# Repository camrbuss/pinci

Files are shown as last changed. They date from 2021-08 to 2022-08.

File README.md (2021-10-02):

# pinci the keyboard 🦐

*pinci pinches panic like popcorn*

This project is still under development, submit an issue if you have questions.

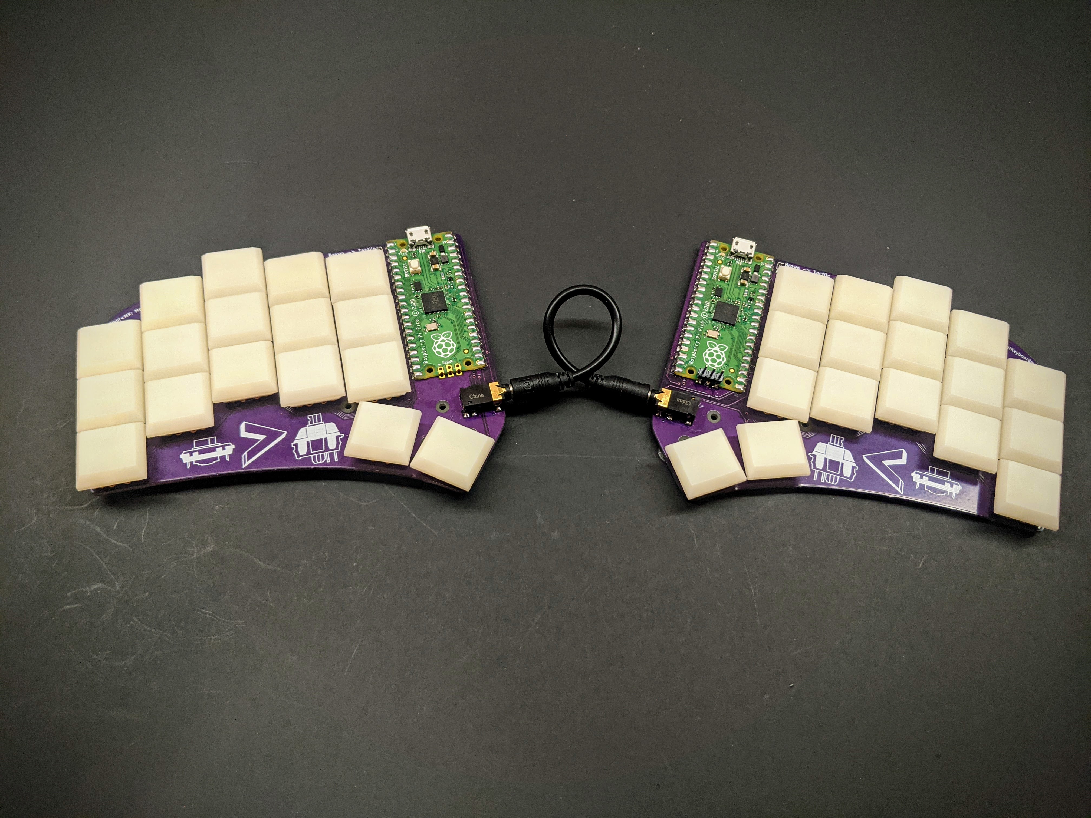
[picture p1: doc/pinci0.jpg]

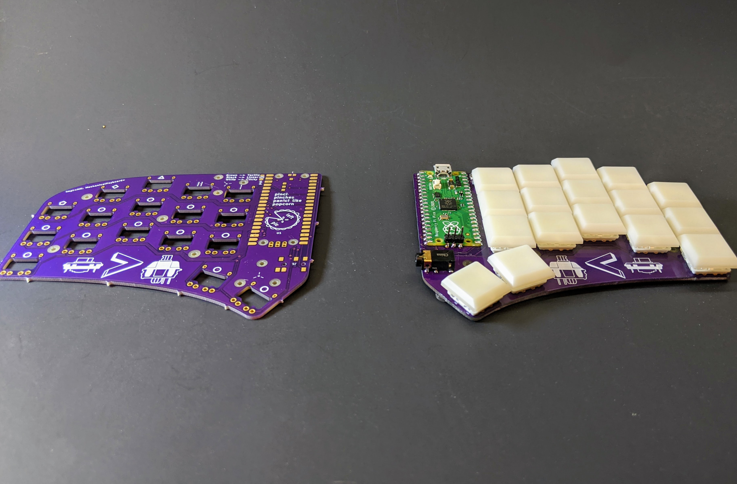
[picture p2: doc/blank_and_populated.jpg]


<p float="left">


</p>

## Hardware

- 34 key layout with two thumb keys skewed outward
- [Kailh PG1232](https://www.kailhswitch.com/news/pg1232-keyboard-switch-brief-introduction-21834938.html) Low Profile Switches
- [Raspberry Pi Pico](https://www.raspberrypi.org/products/raspberry-pi-pico/) (RP2040)
- Reversible PCB
- TRS capable hardware (normal headphone cable)
- Minimal SMD components and no THT components
- No diodes, just direct switch to gpio connections
- Useable with and without a case

### BOM

| Part | Qty | Manufacturer Part No |
| ---- | --- | --- |
| Kailh Swithces | 34 | PG1232 |
| Raspberry Pi Pico | 2 | SC0915 |
| 1206 5% 10k Ohm Resistor | 2 | N/A |
| 3.5mm Headphone Jack | 2 | 54-00177 |

## Firmware

The [firmware](https://github.com/camrbuss/pinci/blob/main/firmware/src/main.rs) is writen in Rust using the following (and more) libraries

- [Keyberon](https://github.com/TeXitoi/keyberon)
- [RTIC](https://github.com/rtic-rs/cortex-m-rtic)
- [rp2040-hal](https://github.com/rp-rs/rp-hal/tree/main/rp2040-hal)

## Inspiration

Thanks to all the open-source projects that have inspired this project

- [Ferris](https://github.com/pierrechevalier83/ferris)
- [Fifi](https://github.com/raychengy/fifi_split_keeb)
- [KeySeeBee](https://github.com/TeXitoi/keyseebee)

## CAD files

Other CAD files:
cad/pinci.FCStd

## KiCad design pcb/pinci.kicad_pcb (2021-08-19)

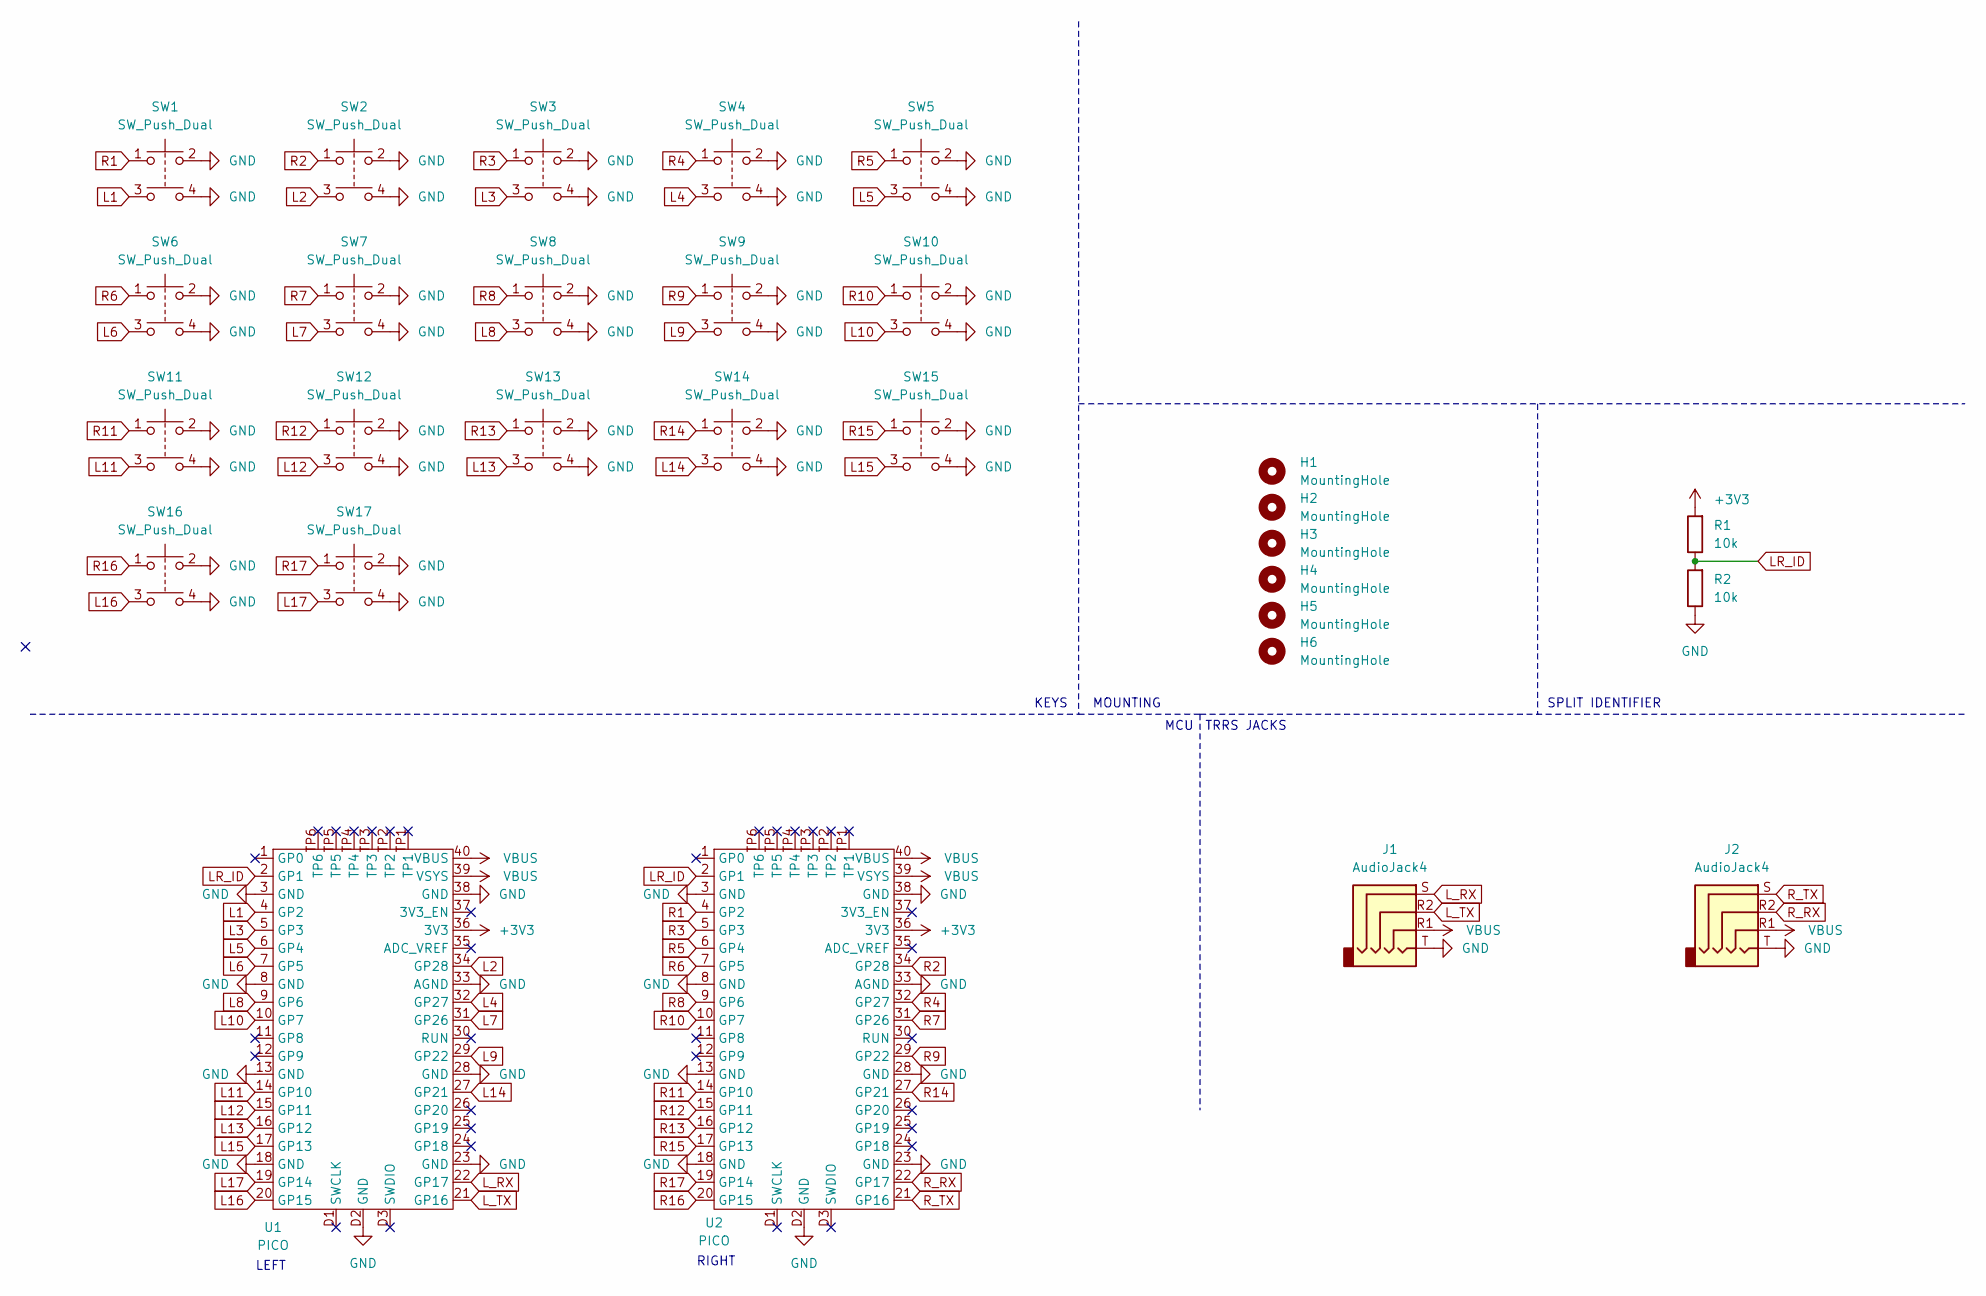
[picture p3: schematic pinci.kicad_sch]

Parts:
H1, H2: MountingHole; 90611A112_Screw_Mount_Nut
H3, H4, H5, H6: MountingHole; M2_Hole
J1, J2: AudioJack4; TRRS_Socket_54-00177
R1, R2: 10k; R_1206_3216Metric_Pad1.30x1.75mm_HandSolder
SW1, SW2, SW3, SW4, SW5, SW6, SW7, SW8, SW9, SW10, SW11, SW12, SW13, SW14, SW15, SW16, SW17: SW_Push_Dual; Kailh_PG1232
U1, U2: PICO; raspberrypi_pico

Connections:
+3V3: R1.2, U1.36 (3V3), U2.36 (3V3)
GND: J1.T, J2.T, R2.1, SW1.2, SW1.4, SW2.2, SW2.4, SW3.2, SW3.4, SW4.2, SW4.4, SW5.2, SW5.4, SW6.2, SW6.4, SW7.2, SW7.4, SW8.2, SW8.4, SW9.2, SW9.4, SW10.2, SW10.4, SW11.2, SW11.4, SW12.2, SW12.4, SW13.2, SW13.4, SW14.2, SW14.4, SW15.2, SW15.4, SW16.2, SW16.4, SW17.2, SW17.4, U1.3 (GND), U1.8 (GND), U1.13 (GND), U1.18 (GND), U1.23 (GND), U1.28 (GND), U1.33 (AGND), U1.38 (GND), U1.D2 (GND), U2.3 (GND), U2.8 (GND), U2.13 (GND), U2.18 (GND), U2.23 (GND), U2.28 (GND), U2.33 (AGND), U2.38 (GND), U2.D2 (GND)
L1: SW1.3, U1.4 (GP2)
L2: SW2.3, U1.34 (GP28)
L3: SW3.3, U1.5 (GP3)
L4: SW4.3, U1.32 (GP27)
L5: SW5.3, U1.6 (GP4)
L6: SW6.3, U1.7 (GP5)
L7: SW7.3, U1.31 (GP26)
L8: SW8.3, U1.9 (GP6)
L9: SW9.3, U1.29 (GP22)
L10: SW10.3, U1.10 (GP7)
L11: SW11.3, U1.14 (GP10)
L12: SW12.3, U1.15 (GP11)
L13: SW13.3, U1.16 (GP12)
L14: SW14.3, U1.27 (GP21)
L15: SW15.3, U1.17 (GP13)
L16: SW16.3, U1.20 (GP15)
L17: SW17.3, U1.19 (GP14)
LR_ID: R1.1, R2.2, U1.2 (GP1), U2.2 (GP1)
L_RX: J1.S, U1.22 (GP17)
L_TX: J1.R2, U1.21 (GP16)
R1: SW1.1, U2.4 (GP2)
R2: SW2.1, U2.34 (GP28)
R3: SW3.1, U2.5 (GP3)
R4: SW4.1, U2.32 (GP27)
R5: SW5.1, U2.6 (GP4)
R6: SW6.1, U2.7 (GP5)
R7: SW7.1, U2.31 (GP26)
R8: SW8.1, U2.9 (GP6)
R9: SW9.1, U2.29 (GP22)
R10: SW10.1, U2.10 (GP7)
R11: SW11.1, U2.14 (GP10)
R12: SW12.1, U2.15 (GP11)
R13: SW13.1, U2.16 (GP12)
R14: SW14.1, U2.27 (GP21)
R15: SW15.1, U2.17 (GP13)
R16: SW16.1, U2.20 (GP15)
R17: SW17.1, U2.19 (GP14)
R_RX: J2.R2, U2.22 (GP17)
R_TX: J2.S, U2.21 (GP16)
VBUS: J1.R1, J2.R1, U1.39 (VSYS), U1.40 (VBUS), U2.39 (VSYS), U2.40 (VBUS)

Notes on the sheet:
LEFT
RIGHT
KEYS
MOUNTING
MCU
TRRS JACKS
SPLIT IDENTIFIER

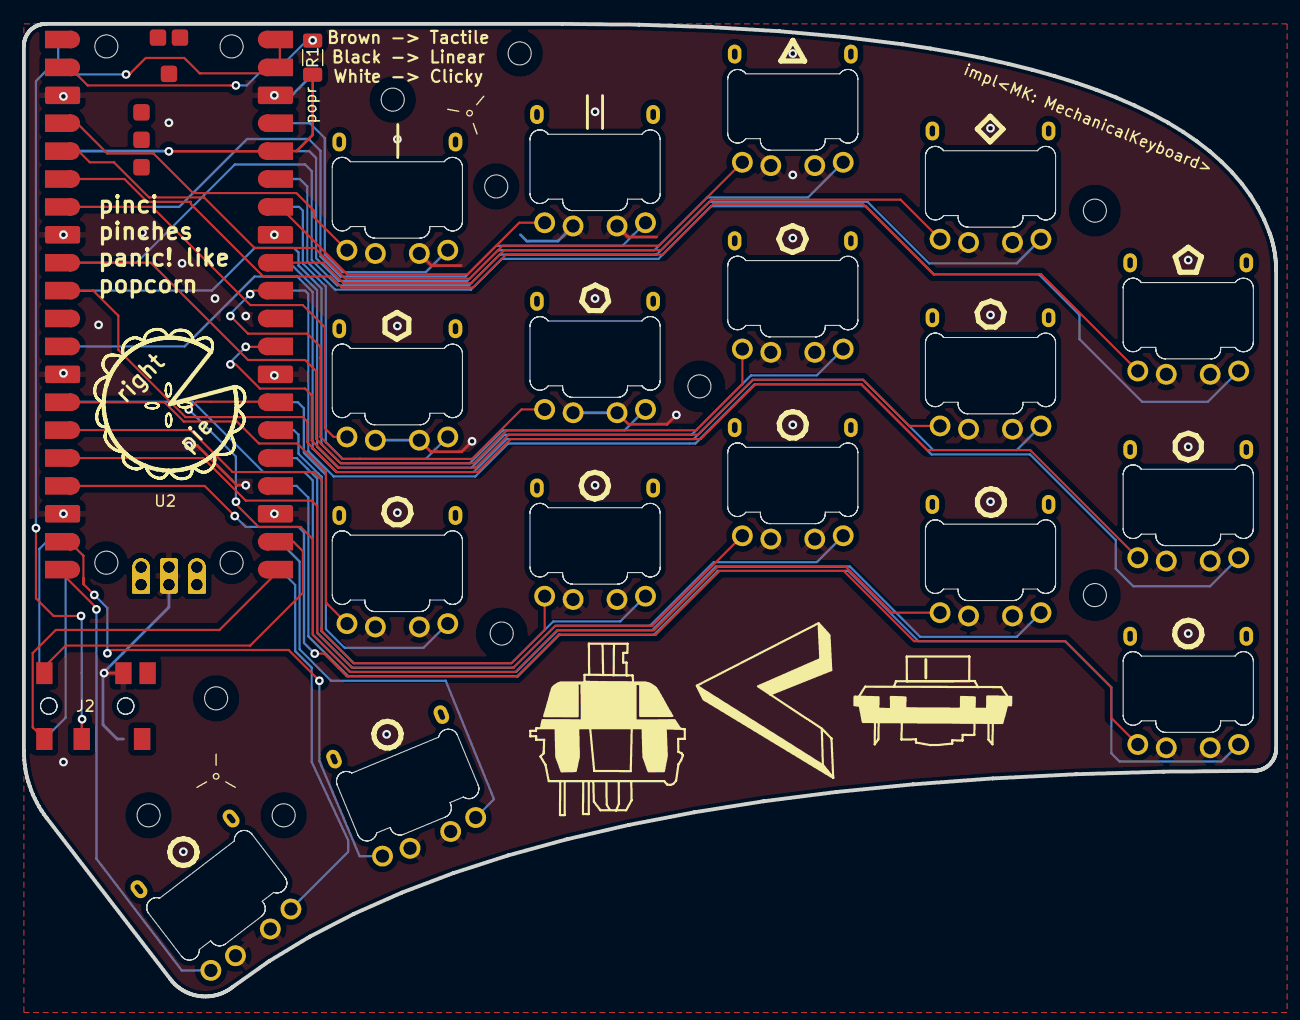
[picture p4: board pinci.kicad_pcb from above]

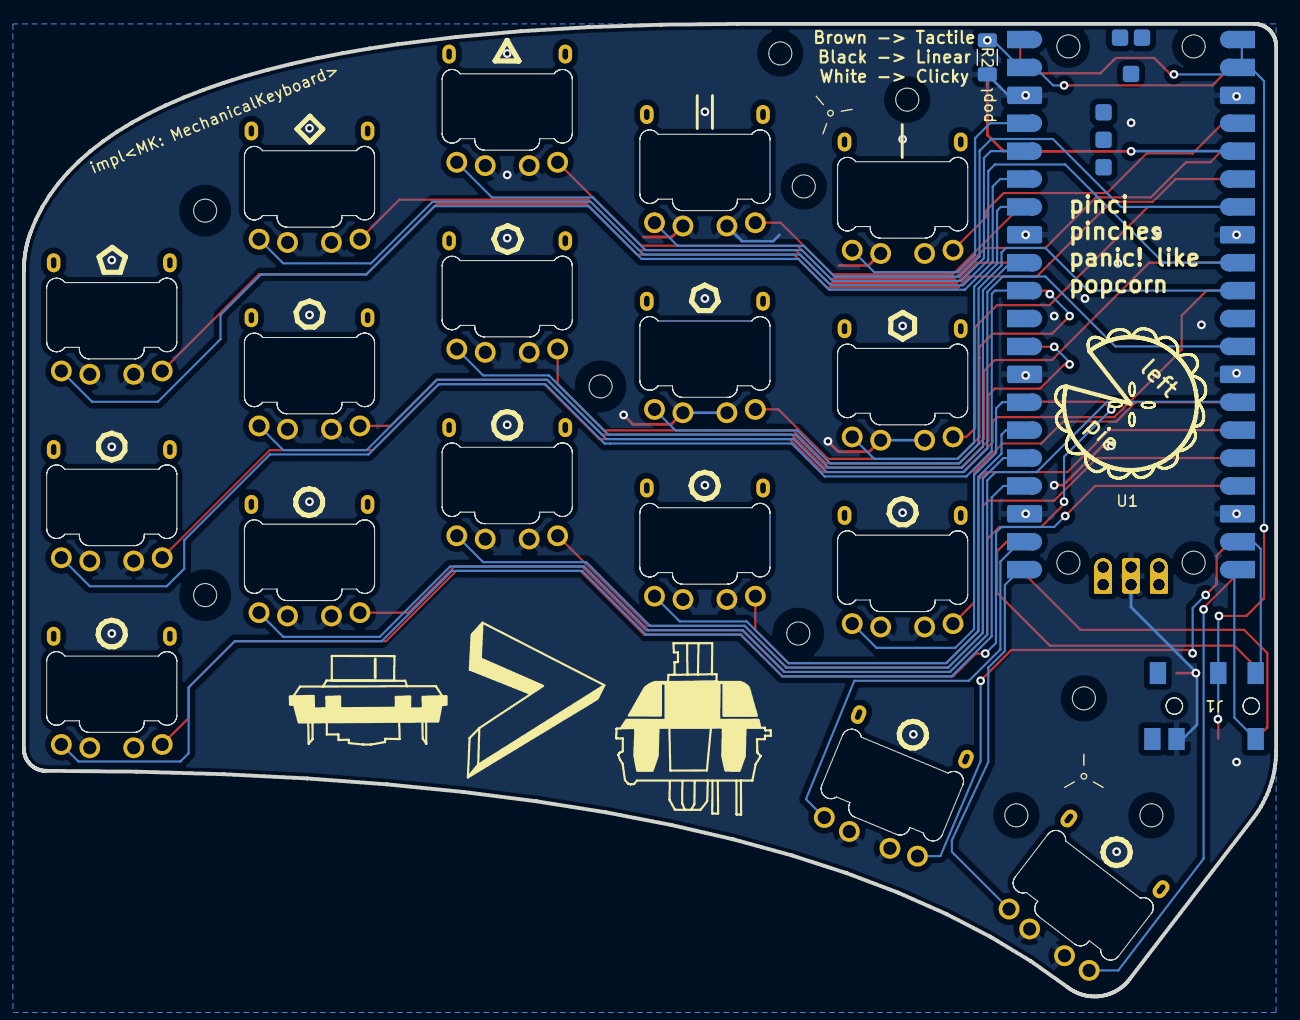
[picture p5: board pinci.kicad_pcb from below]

Board: 2 copper layers, 114.0 x 88.5 mm, 29 parts (5 on the bottom side), 42 nets.

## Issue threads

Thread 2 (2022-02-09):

Kailh Choc switches

hanslenze, 2022-02-09:
Since Kailh Choc Mini switches (PG1232) are so hard to get. Can you make a version that uses "normal" low profile Kailh Choc switches (PG1350)?

camrbuss, 2022-02-10:
It looks like you can still buy the PG1232 on Kailh's aliexpress store. https://www.aliexpress.com/item/32989908397.html?spm=a2g0o.9042311.0.0.40af4c4djiMwT9

If you really want the PG1350, you could definitely just change the footprint and then just update the board. Should be pretty easy.

hanslenze, 2022-02-14:
Thank you so much for that link! I'll make a Choc Mini version when they get to my doorstep.

Closed 2022-02-14.

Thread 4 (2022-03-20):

Mounting holes for what?

hanslenze, 2022-03-20:
I've finally received my PCB order and now I'm wondering what the various mounting holes on this PCB are designed to mount.
Are the two triangular positions meant for a tenting kit? The four holes around the Pico match the Pico itself so they are obvious.
Are the other five holes are for screwing a case to the bottom?

camrbuss, 2022-03-20:
Wow, I'm honored you are taking the dive with the PCB order!

The 5 holes can be used for plate mounting or tenting, and the sets of three are meant to mount one of these nuts (https://www.mcmaster.com/nuts/surface-mount-nuts/)

I never used any of the mount points as I liked keeping it really thin.

Let me know how it works out! I'm happy to work software updates now that someone else has hardware.

camrbuss, 2022-04-01:
@hanslenze Any update or pictures of your build?

hanslenze, 2022-04-01:
I can share my current progress, sure!
Almost all the components have been gathered in a box and now I'm trying to gather enough courage to start the soldering :)
The Pico itself is a bit more SMD soldering so in my head that seems like the hardest part. I've got a temparature controlled soldering iron with a small tip, a fluxpen and 0,6mm resin core solder ready to go.
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

hanslenze, 2022-04-20:
After a few days of use I can say I really like the shape and size of the keyboard but I'm not so sure about the keys themselves. They seem stiff. Maybe it will improve with use, maybe I'll remove the clickbar or lube them or something. Ringfinger and pinky could use a little lighter keys for improved typing comfort and less typing errors. The spit feels great and the column stagger fits my hand very well.
With lots of help from a colleague I've set up the Rust build environment. My first attempt at a keymap can be found on this page: https://github.com/hanslenze/Pinci
The thing I'm missing most is a "mouse mode" where I can move the mouse pointer and use the clicking and scroll keys of a normal mouse. I'm used to that from using a keyboard with QMK. I feel like it is somehow wasteful to use such a powerful chip to only register key presses and nothing else. Maybe I'll add a display or try something else with the pins, memory and processing power that is left on both the Pico's.
Right now it's boring black on black but I'm hoping the fancy coloured MBK keycaps are available at my favorite keyboard shop soon. I've made two of my colleagues happy with a set of PCBs each so they are going to make a Pinci keyboard too.
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

camrbuss, 2022-04-21:
Love the build! Hope it has been fun.

I also can't say I love the switches as far as feel goes. I took my click bars out and it honestly feels even more squishy.

There are some rust/keyberon firmwares out there with mouse emulation so there is opportunity for improvement. I'll try to get this repo updates with firmware with more features.

Have fun playing around!

hanslenze, 2022-11-20:
Just a message to let you know I've made a QMK firmware for the Pinci. I've put a complete version in my Github repo: https://github.com/hanslenze/Pinci-QMK Feel free to copy, use, etc.
Still love the shape, size and features of it so I will be ordering a new batch of PCBs with Kailh Choc hot swap sockets so I can use "normal" low profile keys. Maybe I'll add an I2C header so I can connect a Cirque trackpad. We'll see!

camrbuss, 2022-11-20:
> Just a message to let you know I've made a QMK firmware for the Pinci. I've put a complete version in my Github repo: https://github.com/hanslenze/Pinci-QMK Feel free to copy, use, etc. Still love the shape, size and features of it so I will be ordering a new batch of PCBs with Kailh Choc hot swap sockets so I can use "normal" low profile keys. Maybe I'll add an I2C header so I can connect a Cirque trackpad. We'll see!

Awesome! Thanks for sharing! I'm so glad to see you having fun modifying it. It's lovely to to see some more pinci's in the world.

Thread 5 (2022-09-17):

can gateron low profiles work on the pinci ?

dapppss, 2022-09-17:
im just wondering if they work instead of kailh chocs since gaterons are a bit cheaper.

camrbuss, 2022-10-17:
Sorry, they will not work. Please see the Bill of Materials.

Closed 2022-10-17.

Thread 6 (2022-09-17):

do i need to tweak the specs on pcbway on can i just leave it on deafult

dapppss, 2022-09-17:
i have the gerber file on pcbway but i don't know if i just leave the specs eg size etc. or if i just leave on the defult settings.

camrbuss, 2022-09-24:
> i have the gerber file on pcbway but i don't know if i just leave the specs eg size etc. or if i just leave on the defult settings.

Did you resolve this? I was away when you created the issue.

Closed 2022-09-23.

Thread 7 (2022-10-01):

Are there any build guide?

KentaroKoga, 2022-10-01:
I'm beginner to raspberry pi keyboard so just worried if I can build and set it up properly without guide.
I have experience of building sweep and cantor but not raspberry pi.

I'm sorry if you already put a guide somewhere and I just didn't find it.

Thanks a lot for making this✨

camrbuss, 2022-10-01:
I don't have a build guide as you just solder on the Raspberry Pi Pico, the one resistor (popl or popr), the 3.5mm jack, and then the switches.

Besides soldering the resistor and jack before everything else, there is no special order you need to follow.

I'm happy to answer questions if you decide to attempt the build. If you are new to diy electronics this might not be the best start, but it is certainly possible.

Thanks for the interest! 🦀

KentaroKoga, 2022-10-02:
Thanks for your reply! I think I'll give it a try:)

Closed 2022-10-02.

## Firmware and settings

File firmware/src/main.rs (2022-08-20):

#![no_std]
#![no_main]

use panic_halt as _;

#[rtic::app(device = rp_pico::hal::pac, peripherals = true, dispatchers = [PIO0_IRQ_0])]
mod app {
    use cortex_m::prelude::_embedded_hal_watchdog_Watchdog;
    use cortex_m::prelude::_embedded_hal_watchdog_WatchdogEnable;
    use embedded_hal::digital::v2::{InputPin, OutputPin};
    use embedded_time::duration::units::*;
    use keyberon::action::{k, l, Action, HoldTapAction, HoldTapConfig};
    use keyberon::chording::{ChordDef, Chording};
    use keyberon::debounce::Debouncer;
    use keyberon::key_code::{self, KeyCode::*};
    use keyberon::layout::{self, Layout};
    use keyberon::matrix::Matrix;
    use rp_pico::{
        hal::{
            self, clocks::init_clocks_and_plls, gpio::DynPin, sio::Sio, timer::Alarm, usb::UsbBus,
            watchdog::Watchdog,
        },
        XOSC_CRYSTAL_FREQ,
    };
    use usb_device::class_prelude::*;
    use usb_device::device::UsbDeviceState;

    const SCAN_TIME_US: u32 = 1000;
    static mut USB_BUS: Option<usb_device::bus::UsbBusAllocator<rp2040_hal::usb::UsbBus>> = None;

    #[derive(Debug, Clone, Copy, Eq, PartialEq)]
    pub enum CustomActions {
        Uf2,
        Reset,
    }
    const UF2: Action<CustomActions> = Action::Custom(CustomActions::Uf2);
    const RESET: Action<CustomActions> = Action::Custom(CustomActions::Reset);

    const QW_ESC: ChordDef = ((0, 37), &[(0, 0), (0, 1)]);
    const JU_ESC: ChordDef = ((0, 37), &[(0, 16), (0, 6)]);
    const KI_TAB: ChordDef = ((0, 39), &[(0, 17), (0, 7)]);
    const LO_ENTER: ChordDef = ((0, 38), &[(0, 18), (0, 8)]);
    const CHORDS: [ChordDef; 4] = [QW_ESC, JU_ESC, KI_TAB, LO_ENTER];

    const A_LSHIFT: Action<CustomActions> = Action::HoldTap(&HoldTapAction {
        timeout: 200,
        hold: k(LShift),
        tap: k(A),
        config: HoldTapConfig::PermissiveHold,
        tap_hold_interval: 0,
    });
    const L5_S: Action<CustomActions> = Action::HoldTap(&HoldTapAction {
        timeout: 200,
        hold: l(5),
        tap: k(S),
        config: HoldTapConfig::Default,
        tap_hold_interval: 0,
    });
    const D_LALT: Action<CustomActions> = Action::HoldTap(&HoldTapAction {
        timeout: 200,
        hold: k(LAlt),
        tap: k(D),
        config: HoldTapConfig::Default,
        tap_hold_interval: 0,
    });
    const L2_F: Action<CustomActions> = Action::HoldTap(&HoldTapAction {
        timeout: 200,
        hold: l(2),
        tap: k(F),
        config: HoldTapConfig::Default,
        tap_hold_interval: 0,
    });
    const DOT_RALT: Action<CustomActions> = Action::HoldTap(&HoldTapAction {
        timeout: 200,
        hold: k(RAlt),
        tap: k(Dot),
        config: HoldTapConfig::Default,
        tap_hold_interval: 0,
    });
    const X_LALT: Action<CustomActions> = Action::HoldTap(&HoldTapAction {
        timeout: 200,
        hold: k(LAlt),
        tap: k(X),
        config: HoldTapConfig::Default,
        tap_hold_interval: 0,
    });
    const SLASH_RCTRL: Action<CustomActions> = Action::HoldTap(&HoldTapAction {
        timeout: 200,
        hold: k(RCtrl),
        tap: k(Slash),
        config: HoldTapConfig::Default,
        tap_hold_interval: 0,
    });
    const Z_LCTRL: Action<CustomActions> = Action::HoldTap(&HoldTapAction {
        timeout: 200,
        hold: k(LCtrl),
        tap: k(Z),
        config: HoldTapConfig::Default,
        tap_hold_interval: 0,
    });
    const L4_C: Action<CustomActions> = Action::HoldTap(&HoldTapAction {
        timeout: 200,
        hold: l(4),
        tap: k(C),
        config: HoldTapConfig::Default,
        tap_hold_interval: 0,
    });
    const SEMI_RSHIFT: Action<CustomActions> = Action::HoldTap(&HoldTapAction {
        timeout: 200,
        hold: k(RShift),
        tap: k(SColon),
        config: HoldTapConfig::PermissiveHold,
        tap_hold_interval: 0,
    });
    const L7_SPACE: Action<CustomActions> = Action::HoldTap(&HoldTapAction {
        timeout: 200,
        hold: l(7),
        tap: k(Space),
        config: HoldTapConfig::Default,
        tap_hold_interval: 0,
    });
    const L4_COMMA: Action<CustomActions> = Action::HoldTap(&HoldTapAction {
        timeout: 200,
        hold: l(4),
        tap: k(Comma),
        config: HoldTapConfig::Default,
        tap_hold_interval: 0,
    });

    #[rustfmt::skip]
    pub static LAYERS: keyberon::layout::Layers<40, 1, 8, CustomActions> = keyberon::layout::layout! {
    {[ // 0
        Q          W        E        R      T      Y          U   I          O          P
        {A_LSHIFT} {L5_S}   {D_LALT} {L2_F} G      H          J   K          L          {SEMI_RSHIFT}
        {Z_LCTRL}  {X_LALT} {L4_C}   V      B      N          M   {L4_COMMA} {DOT_RALT} {SLASH_RCTRL}
        t          t        t        (3)    BSpace {L7_SPACE} Tab Escape     Enter      Tab
    ]}
    {[ // 1
        t t t t t t t t t t
        t t t t t t t t t t
        t t t t t t t t t t
        t t t t t t t t t t
    ]}
    {[ // 2
        t t t t t * 7 8 9 +
        t t t t t / 4 5 6 -
        t t t t t . 1 2 3 .
        t t t t t 0 0 t t t
    ]}
    {[ // 3
        t 7 8 9 t t t t t t
        t 4 5 6 t t t t t t
        0 1 2 3 t t t t t t
        t t t t t t t t t t
    ]}
    {[ // 4
        !   @   #   $   % t ~   |    '`' +
        '{' '}' '(' ')' t = '_' -    '"' Quote
        '[' ']' ^   &   * t /   '\\' t   t
        t   t   t   t   t t t   t    t   t
    ]}
    {[ // 5
        t t t      t t t    t    PgUp   t     t
        t t Delete t t Left Down Up     Right Enter
        t t t      t t t    Home PgDown End   t
        t t t      t t t    t    t      t     t
    ]}
    {[ // 6
        {RESET} {UF2} t t t t t t t MediaSleep
        t       t     t t t t t t t t
        t       t     t t t t t t t t
        t       t     t t t t t t t t
    ]}
    {[ // 7
        t t t t t      MediaNextSong MediaPlayPause MediaVolDown MediaVolUp PScreen
        t t t t t      t             Escape         Tab          Enter      Enter
        t t t t t      t             t              t            t          Delete
        t t t t Delete t             t              t            t          t
    ]}

};

    #[shared]
    struct Shared {
        usb_dev: usb_device::device::UsbDevice<'static, rp2040_hal::usb::UsbBus>,
        usb_class: keyberon::hid::HidClass<
            'static,
            rp2040_hal::usb::UsbBus,
            keyberon::keyboard::Keyboard<()>,
        >,
        uart: rp2040_hal::pac::UART0,
        layout: Layout<40, 1, 8, CustomActions>,
    }

    #[local]
    struct Local {
        watchdog: hal::watchdog::Watchdog,
        chording: Chording<4>,
        matrix: Matrix<DynPin, DynPin, 17, 1>,
        debouncer: Debouncer<[[bool; 17]; 1]>,
        alarm: hal::timer::Alarm0,
        transform: fn(layout::Event) -> layout::Event,
        is_right: bool,
    }

    #[init]
    fn init(c: init::Context) -> (Shared, Local, init::Monotonics) {
        // Soft-reset does not release the hardware spinlocks
        // Release them now to avoid a deadlock after debug or watchdog reset
        unsafe {
            hal::sio::spinlock_reset();
        }
        let mut resets = c.device.RESETS;
        let mut watchdog = Watchdog::new(c.device.WATCHDOG);
        let clocks = init_clocks_and_plls(
            XOSC_CRYSTAL_FREQ,
            c.device.XOSC,
            c.device.CLOCKS,
            c.device.PLL_SYS,
            c.device.PLL_USB,
            &mut resets,
            &mut watchdog,
        )
        .ok()
        .unwrap();

        let sio = Sio::new(c.device.SIO);
        let pins = hal::gpio::Pins::new(
            c.device.IO_BANK0,
            c.device.PADS_BANK0,
            sio.gpio_bank0,
            &mut resets,
        );

        // 17 input pins and 1 empty pin that is not really used, but
        // is needed by keyberon as a "row"
        let gpio2 = pins.gpio2;
        let gpio28 = pins.gpio28;
        let gpio3 = pins.gpio3;
        let gpio27 = pins.gpio27;
        let gpio4 = pins.gpio4;
        let gpio5 = pins.gpio5;
        let gpio26 = pins.gpio26;
        let gpio6 = pins.gpio6;
        let gpio22 = pins.gpio22;
        let gpio7 = pins.gpio7;
        let gpio10 = pins.gpio10;
        let gpio11 = pins.gpio11;
        let gpio12 = pins.gpio12;
        let gpio21 = pins.gpio21;
        let gpio13 = pins.gpio13;
        let gpio15 = pins.gpio15;
        let gpio14 = pins.gpio14;

        let gpio20 = pins.gpio20;

        let mut led = pins.gpio25.into_push_pull_output();
        // GPIO1 is high for the right hand side
        let side = pins.gpio1.into_floating_input();
        // delay for power on
        for _ in 0..1000 {
            cortex_m::asm::nop();
        }

        // Use a transform to get correct layout from right and left side
        let is_right = side.is_high().unwrap();
        let transform: fn(layout::Event) -> layout::Event = if is_right {
            |e| {
                e.transform(|i: u8, j: u8| -> (u8, u8) {
                    // 0 -> 5,  5 -> 15, 10 -> 25
                    let x = ((j / 5) * 10) + (j % 5) + 5;
                    (i, x)
                })
            }
        } else {
            |e| {
                e.transform(|i: u8, j: u8| -> (u8, u8) {
                    let x = ((j / 5) * 10) + 4 - (j % 5);
                    (i, x)
                })
            }
        };

        // Enable UART0
        resets.reset.modify(|_, w| w.uart0().clear_bit());
        while resets.reset_done.read().uart0().bit_is_clear() {}
        let uart = c.device.UART0;
        uart.uartibrd.write(|w| unsafe { w.bits(0b0100_0011) });
        uart.uartfbrd.write(|w| unsafe { w.bits(0b0011_0100) });
        uart.uartlcr_h.write(|w| unsafe { w.bits(0b0110_0000) });
        uart.uartcr.write(|w| unsafe { w.bits(0b11_0000_0001) });
        uart.uartimsc.write(|w| w.rxim().set_bit());

        let matrix: Matrix<DynPin, DynPin, 17, 1> = Matrix::new(
            [
                gpio2.into_pull_up_input().into(),
                gpio28.into_pull_up_input().into(),
                gpio3.into_pull_up_input().into(),
                gpio27.into_pull_up_input().into(),
                gpio4.into_pull_up_input().into(),
                gpio5.into_pull_up_input().into(),
                gpio26.into_pull_up_input().into(),
                gpio6.into_pull_up_input().into(),
                gpio22.into_pull_up_input().into(),
                gpio7.into_pull_up_input().into(),
                gpio10.into_pull_up_input().into(),
                gpio11.into_pull_up_input().into(),
                gpio12.into_pull_up_input().into(),
                gpio21.into_pull_up_input().into(),
                gpio13.into_pull_up_input().into(),
                gpio15.into_pull_up_input().into(),
                gpio14.into_pull_up_input().into(),
            ],
            [gpio20.into_push_pull_output().into()],
        )
        .unwrap();

        let layout = Layout::new(&LAYERS);
        let debouncer = Debouncer::new([[false; 17]; 1], [[false; 17]; 1], 20);

        let chording = Chording::new(&CHORDS);

        let mut timer = hal::Timer::new(c.device.TIMER, &mut resets);
        let mut alarm = timer.alarm_0().unwrap();
        let _ = alarm.schedule(SCAN_TIME_US.microseconds());
        alarm.enable_interrupt();

        // TRS cable only supports one direction of communication
        if is_right {
            let _rx_pin = pins.gpio17.into_mode::<hal::gpio::FunctionUart>();
            led.set_high().unwrap();
        } else {
            let _tx_pin = pins.gpio16.into_mode::<hal::gpio::FunctionUart>();
        }

        let usb_bus = UsbBusAllocator::new(UsbBus::new(
            c.device.USBCTRL_REGS,
            c.device.USBCTRL_DPRAM,
            clocks.usb_clock,
            true,
            &mut resets,
        ));
        unsafe {
            USB_BUS = Some(usb_bus);
        }
        let usb_class = keyberon::new_class(unsafe { USB_BUS.as_ref().unwrap() }, ());
        let usb_dev = keyberon::new_device(unsafe { USB_BUS.as_ref().unwrap() });

        // Start watchdog and feed it with the lowest priority task at 1000hz
        watchdog.start(10_000.microseconds());

        (
            Shared {
                usb_dev,
                usb_class,
                uart,
                layout,
            },
            Local {
                alarm,
                chording,
                watchdog,
                matrix,
                debouncer,
                transform,
                is_right,
            },
            init::Monotonics(),
        )
    }

    #[task(binds = USBCTRL_IRQ, priority = 3, shared = [usb_dev, usb_class])]
    fn usb_rx(c: usb_rx::Context) {
        let mut usb_d = c.shared.usb_dev;
        let mut usb_c = c.shared.usb_class;
        usb_d.lock(|d| {
            usb_c.lock(|c| {
                if d.poll(&mut [c]) {
                    c.poll();
                }
            })
        });
    }

    #[task(priority = 2, capacity = 8, shared = [usb_dev, usb_class, layout])]
    fn handle_event(mut c: handle_event::Context, event: Option<layout::Event>) {
        match event {
            // TODO: Support Uf2 for the side not performing USB HID
            // The right side only passes None here and buffers the keys
            // for USB to send out when polled by the host
            None => match c.shared.layout.lock(|l| l.tick()) {
                layout::CustomEvent::Press(event) => match event {
                    CustomActions::Uf2 => {
                        hal::rom_data::reset_to_usb_boot(0, 0);
                    }
                    CustomActions::Reset => {
                        cortex_m::peripheral::SCB::sys_reset();
                    }
                },
                _ => (),
            },
            Some(e) => {
                c.shared.layout.lock(|l| l.event(e));
                return;
            }
        };
        let report: key_code::KbHidReport = c.shared.layout.lock(|l| l.keycodes().collect());
        if !c
            .shared
            .usb_class
            .lock(|k| k.device_mut().set_keyboard_report(report.clone()))
        {
            return;
        }
        if c.shared.usb_dev.lock(|d| d.state()) != UsbDeviceState::Configured {
            return;
        }
        while let Ok(0) = c.shared.usb_class.lock(|k| k.write(report.as_bytes())) {}
    }

    #[task(
        binds = TIMER_IRQ_0,
        priority = 1,
        shared = [uart],
        local = [matrix, debouncer, chording, watchdog, alarm, transform, is_right],
    )]
    fn scan_timer_irq(mut c: scan_timer_irq::Context) {
        let alarm = c.local.alarm;
        alarm.clear_interrupt();
        let _ = alarm.schedule(SCAN_TIME_US.microseconds());

        c.local.watchdog.feed();
        let keys_pressed = c.local.matrix.get().unwrap();
        let deb_events = c
            .local
            .debouncer
            .events(keys_pressed)
            .map(c.local.transform);
        // TODO: right now chords cannot only be exclusively on one side
        let events = c.local.chording.tick(deb_events.collect()).into_iter();

        // TODO: With a TRS cable, we can only have one device support USB
        if *c.local.is_right {
            for event in events {
                handle_event::spawn(Some(event)).unwrap();
            }
            handle_event::spawn(None).unwrap();
        } else {
            // coordinate and press/release is encoded in a single byte
            // the first 6 bits are the coordinate and therefore cannot go past 63
            // The last bit is to signify if it is the last byte to be sent, but
            // this is not currently used as serial rx is the highest priority
            // end? press=1/release=0 key_number
            //   7         6            543210
            let mut es: [Option<layout::Event>; 16] = [None; 16];
            for (i, e) in events.enumerate() {
                es[i] = Some(e);
            }
            let stop_index = es.iter().position(|&v| v == None).unwrap();
            for i in 0..(stop_index + 1) {
                let mut byte: u8;
                if let Some(ev) = es[i] {
                    if ev.coord().1 <= 0b0011_1111 {
                        byte = ev.coord().1;
                    } else {
                        byte = 0b0011_1111;
                    }
                    byte |= (ev.is_press() as u8) << 6;
                    if i == stop_index + 1 {
                        byte |= 0b1000_0000;
                    }
                    // Watchdog will catch any possibility for an infinite loop
                    while c.shared.uart.lock(|u| u.uartfr.read().txff().bit_is_set()) {}
                    c.shared
                        .uart
                        .lock(|u| u.uartdr.write(|w| unsafe { w.data().bits(byte) }));
                }
            }
        }
    }

    #[task(binds = UART0_IRQ, priority = 4, shared = [uart])]
    fn rx(mut c: rx::Context) {
        // RX FIFO is disabled so we just check that the byte received is valid
        // and then we read it. If a bad byte is received, it is possible that the
        // receiving side will never read. TODO: fix this
        if c.shared.uart.lock(|u| {
            u.uartmis.read().rxmis().bit_is_set()
                && u.uartfr.read().rxfe().bit_is_clear()
                && u.uartdr.read().oe().bit_is_clear()
                && u.uartdr.read().be().bit_is_clear()
                && u.uartdr.read().pe().bit_is_clear()
                && u.uartdr.read().fe().bit_is_clear()
        }) {
            let d: u8 = c.shared.uart.lock(|u| u.uartdr.read().data().bits());
            if (d & 0b01000000) > 0 {
                handle_event::spawn(Some(layout::Event::Press(0, d & 0b0011_1111))).unwrap();
            } else {
                handle_event::spawn(Some(layout::Event::Release(0, d & 0b0011_1111))).unwrap();
            }
        }
    }
}

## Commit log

2021-08-09 board edge and silkscreen
    [pinci.FCStd, pinci.kicad_pcb, pinci.kicad_sch]
2021-08-16 footprint positions prelim
    [pinci.kicad_pcb, pinci.kicad_sch]
2021-08-16 switches prelim routed
    [pinci.kicad_pcb, pinci.kicad_sch]
2021-08-17 routing rc
    [pinci.kicad_pcb, pinci.kicad_sch]
2021-08-17 drc fixes
    [pinci.kicad_pcb]
2021-08-19 pinci pcb 0.1
    [pinci.kicad_pcb, pinci.kicad_sch]
2021-09-26 Register level UART for split comms
2021-10-02 Add BOM with part no's
2021-12-18 Updated all dependencies to their latest versions (where possible) and fixed the code to work with them. Also fixed Keberon dep inside Cargo.toml.
    [main.rs]
2021-12-19 timer hal
